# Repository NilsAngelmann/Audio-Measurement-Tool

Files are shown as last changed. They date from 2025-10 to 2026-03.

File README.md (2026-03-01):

# About

This fork focuses on the **stand-alone audio measurement tool** that was originally developed as part of the [“Making Music over the Internet”](https://github.com/StephanBorucki/MusizierenUeberDasInternet) project.

Here you will find detailed information such as the schematic, PCB layout, bill of materials, Arduino sketches, and usage instructions.

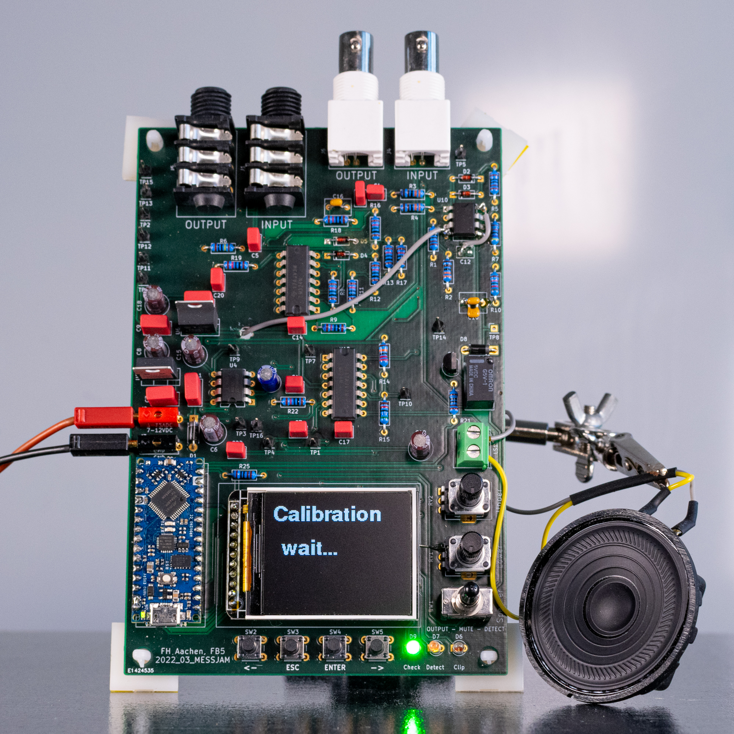
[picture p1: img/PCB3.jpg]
PCB


---

## Demo Video on YouTube 📺
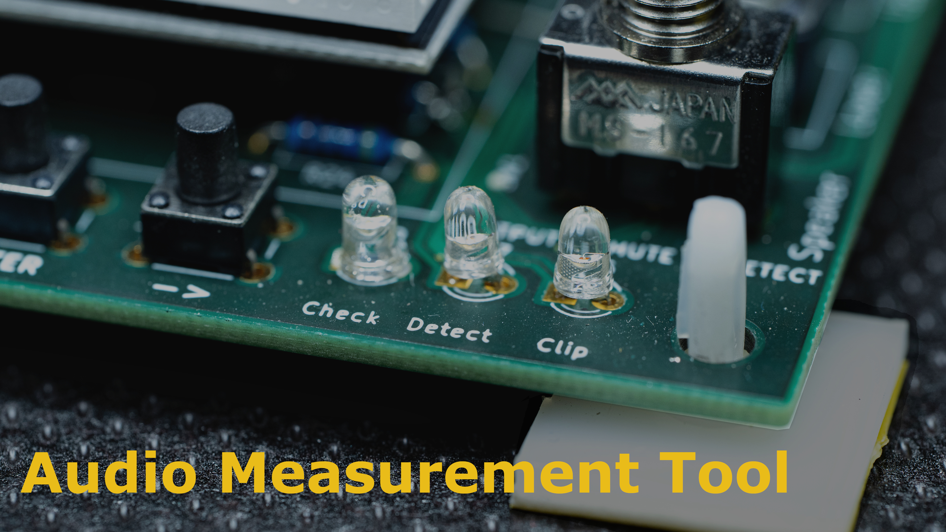
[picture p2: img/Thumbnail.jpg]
YouTube Video (https://www.youtube.com/watch?v=QHqr9eeyrQI)


---
## Files
- **Hardware:**
  - [2022](hardware/2022): Original version from 2022
    - Created with KiCad 8
    - Comments in German
    - Includes: Schematic, PCB Layout, Gerber Files, BOM
      
  - [2025](hardware/2025): Published version with corrections
    - Created with KiCad 9
    - Comments in English
    - Includes: Schematic
      
- **Firmware:**
  - [Measurement_03:](firmware/Measurement_03): Version 1.3
    - Measurement_03.ino: imports, pins, constants, variables, main loop of state machine
    - a_setup.ino: pin modes, welcome message on screen
    - b_menu.ino: menu to choose between error detection (DETECT) and latency measurement (BURST) mode
    - c_detect.ino: error detection (DETECT) mode
    - d_burst.ino: latency measurement (BURST) mode
   
> [!NOTE]
> Please refer to [Info2022](hardware/2022/Info2022.md) and [Info2025](hardware/2025/Info2025.md) before attempting to recreate this setup.

---
### License
This project is licensed under the [CERN Open Hardware License Version 2 – Permissive (CERN-OHL-P)](https://cern-ohl.web.cern.ch/).

Note: This license applies to the hardware design and firmware hosted here.
The printed article and its photos as published in Elektor remain subject to Elektor’s publishing rights.

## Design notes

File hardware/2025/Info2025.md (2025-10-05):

## Info regarding the corrected schematic

> [!IMPORTANT]
> This is only an updated schematic that does not include an updated pcb layout.

> [!TIP]
> This version should be used as a basis for all future revisions.

The following issues from the original version have been fixed in this update:
- [x] Supply voltage: 7 to 7.5 VDC rather than 7 to 12 VDC
- [ ] Switch SW1: Annotation flipped (should be output/mute/detect left to right) -> pcb layout (silkscreen)
- [ ] Polarity of electrolytic capacitors: No visible marking -> pcb layout (silkscreen)
- [ ] Test points: Only numbers -> pcb layout (silkscreen)
- [ ] Display footprint: Missing an unused pin -> only important for integtrated SD card reader
- [ ] DIP footprints: Too wide -> pcb layout
- [x] U10 (op amp): V+ and V- swapped
- [x] D5: wrong polarity
- [x] Clipping comparator: inputs swapped
- [x] Display SPI: MOSI and MISO swapped
- [ ] LED brightness -> adjust current-limiting resistors to taste

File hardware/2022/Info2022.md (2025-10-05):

## Info regarding the original version of the PCB from 2022

> [!CAUTION]
> This is the original version that includes several errors!

> [!WARNING]
> It is not advised to use this version as is!

- Supply voltage: 7 to 7.5 VDC rather than 7 to 12 VDC
- Switch SW1: Annotation flipped - should be output/mute/detect (left to right)
- Polarity of electrolytic capacitors: No visible marking - use GND plane as reference
- Test points: Only numbers - crossreference schematic for functions
- Display footprint: Missing an unused pin - ignore
- DIP footprints: Too wide - bend legs slightly appart, do not use sockets
- U10 (op amp): V+ and V- swapped - bend legs up and connect using wire
- D5: wrong polarity - solder in with opposing polarity
- Clipping comparator: inputs swapped - turn LED around and connect anode to +5V
- Display SPI: MOSI and MISO swapped - bridge both Arduino pins (MISO is not needed)
- LED brightness: depending on the used LEDs adjust their current-limiting resistors

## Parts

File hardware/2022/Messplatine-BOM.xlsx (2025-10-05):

Ref | Value | Quantity | Link
A1 | TFT-1.8-ST7735R | 1 | https://www.reichelt.de/entwicklerboards-display-led-1-8-128x160-st7735r-debo-tft-1-8-p192139.html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
A2 | Arduino_Nano_Every | 1 | https://www.reichelt.de/arduino-nano-every-atmega4809-mit-header-ard-nano-eve-h-p261301.html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
A | Header | 2 | https://www.reichelt.de/50pol-stiftleiste-gerade-rm-2-54-sl-1x50g-2-54-p19508.html?trstct=pol_0&nbc=1
A | Sockets | 3 | https://www.reichelt.de/20pol-buchsenleiste-gerade-rm-2-54-bl-1x20g-2-54-p6072.html?trstct=pol_1&nbc=1
C1 C5 C7 C12 C14 C17 C20 C22 | 100n | 8 | https://www.reichelt.de/mks02-pet-kondensator-100-nf-10-63-vdc-rm-2-5-mks02-63-100n-p12314.html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
C10 | 1n5 | 1 | https://www.reichelt.de/mks2-pet-kondensator-1-5-f-5-63-vdc-rm-5-mks2-63-1-5--p12348.html?trstct=pol_0&nbc=1
C13 | 10u | 1 | https://www.reichelt.de/elko-radial-10-f-16-v-rm-2-5-85-c-2000-h-20--m-a-10u-16-3-p228236.html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
C16 | 22p | 1 | https://www.reichelt.de/vielschicht-kerko-22pf-200v-125-c-c3c0g-22p-200-p206825.html?trstct=pos_4&nbc=1
C2 C4 | 47n | 2 | https://www.reichelt.de/mks02-pet-kondensator-47-nf-10-63-vdc-rm-2-5-mks02-63-47n-p12326.html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
C3 C9 C11 C21 | 470n | 4 | https://www.reichelt.de/folienkondensator-470nf-63v-rm5-mks2-63-470n-p12357.html?&trstct=pol_0&nbc=1
C6 C8 C15 C18 C19 | 100u | 5 | https://www.reichelt.de/elko-radial-100-f-16-v-rm-2-5-85-c-2000h-20--rad-100-16-p15101.html?trstct=pol_0&nbc=1
D1 D8 | 1N4001 | 2 | https://www.reichelt.de/gleichrichterdiode-50-v-1-a-do-41-1n-4001-p1723.html?&trstct=pos_0&nbc=1
D2 D3 D4 D5 | 1N4148 | 4 | https://www.reichelt.de/schalt-diode-100-v-150-ma-do-35-1n-4148-p1730.html?&trstct=pos_0&nbc=1
D6 | LED, green | 1 | https://www.reichelt.de/led-3-mm-bedrahtet-gruen-6500-mcd-30--wue-151033gs0300-p230890.html?trstct=pol_1&nbc=1
D7 | LED, yellow | 1 | https://www.reichelt.de/led-3-mm-bedrahtet-gelb-850-mcd-30--wue-151033ys0300-p230892.html?trstct=pol_5&nbc=1
D8 | LED, red | 1 | https://www.reichelt.de/led-3-mm-bedrahtet-rot-850-mcd-30--wue-151033rs0300-p230891.html?trstct=pol_4&nbc=1
J1 J5 | TRS | 2 | https://www.reichelt.de/klinkeneinbaubuchse-6-35-mm-stereo-neutrik-nr-j6hf-p116984.html?trstct=pol_9&nbc=1
J2 | SKS-MPB1, black | 1 | https://www.reichelt.de/miniatur-pruefbuchse-2-mm-schwarz-mpb-1-sw-p12711.html?&trstct=pol_3&nbc=1
J3 | SKS-MPB1, red | 1 | https://www.reichelt.de/miniatur-pruefbuchse-2-mm-rot-mpb-1-rt-p12710.html?&trstct=pol_2&nbc=1
J4 J6 | BNC | 2 | https://www.reichelt.de/bnc-printeinbaubuchse-gewinkelt-50-ohm-ug-1094w1-p22018.html?trstct=pol_4&nbc=1
K1 | SPDT | 1 | https://www.reichelt.de/signalrelais-thd-5-vdc-1-a-1-wechsler-g5v-1-5dc-p243067.html?trstct=pol_3&nbc=1
LS1 | Screw terminal | 1 | https://www.reichelt.de/anschlussklemme-2-pol-rm-5-08-mm-90--lakl-1-5-2-5-08-p169871.html?trstct=pol_1&nbc=1
LS | loudspeaker | 1 | https://www.reichelt.de/kleinlautsprecher-lsm-50m-k-f-0-5w-50ohm-lsm-50m-k-f-p145865.html?trstct=pol_6&nbc=1
Q1 | BC550 | 1 | https://www.reichelt.de/bipolartransistor-npn-45v-0-1a-hfe-420-800-0-625w-to-9-bc-550c-p5014.html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
R1 R5 R21 R25 | 1k | 4 | https://www.reichelt.de/widerstand-metallschicht-1-00-kohm-0207-0-6-w-1--metall-1-00k-p11403.html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
R10 | 82k | 1 | https://www.reichelt.de/widerstand-metallschicht-82-0-kohm-0207-0-6-w-1--metall-82-0k-p11999.html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
R14 | 220k | 1 | https://www.reichelt.de/widerstand-metallschicht-220-kohm-0207-0-6-w-1--metall-220k-p11628.html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
R15 | 56k | 1 | https://www.reichelt.de/widerstand-metallschicht-56-0-kohm-0207-0-6-w-1--metall-56-0k-p11879.html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
R2 R3 R4 | 3k3 | 3 | https://www.reichelt.de/widerstand-metallschicht-3-30-kohm-0207-0-6-w-1--metall-3-30k-p11693.html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
R20 R23 R24 | 4k7 | 3 | https://www.reichelt.de/widerstand-metallschicht-4-70-kohm-0207-0-6-w-1--metall-4-70k-p11784.html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
R6 | 1M | 1 | https://www.reichelt.de/widerstand-metallschicht-1-0-mohm-0207-0-6-w-1--metall-1-00m-p11404.html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
R7 | 47k | 1 | https://www.reichelt.de/widerstand-metallschicht-47-0-kohm-0207-0-6-w-1--metall-47-0k-p11823.html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
R8 R9 R11 R12 R13 R16 R17 R18 R19 R22 | 10k | 10 | https://www.reichelt.de/widerstand-metallschicht-10-0-kohm-0207-0-6-w-1--metall-10-0k-p11449.html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
RV1 RV2 | 100k | 2 | https://www.reichelt.de/drehpotentiometer-mono-100-kohm-linear-6-mm-rk09k113-lin100k-p73818.html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
SW1 | ON-OFF-ON | 1 | https://www.reichelt.de/kippschalter-6-a-125-vac-1x-ein-aus-ein-ms-167-p13141.html?trstct=pol_1&nbc=1
SW2 SW3 SW4 SW5 | SW_Push | 4 | https://www.reichelt.de/kurzhubtaster-6x6mm-hoehe-8-0mm-12v-vertikal-taster-9305-p44586.html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
U10 | LM358 | 1 | https://www.reichelt.de/operationsverstaerker-2-fach-0-4-v-s-700-khz-pdip-8-lm-358-p-p187547.html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
U0 | (Socket DIP8) | 1 | https://www.reichelt.de/praezisionsfassung-8-polig-rm-2-54-mpe-001-1-008-3-p213777.html?trstct=pol_2&nbc=1
U11 U12 | LM324 | 2 | https://www.reichelt.de/operationsverstaerker-quad-1-2-mhz-dil-14-lm-324-n-p248019.html?trstct=pos_2&nbc=1
U0 | (Socket DIP14) | 2 | https://www.reichelt.de/praezisionsfassung-14-polig-rm-2-54-mpe-001-1-014-3-p213779.html?trstct=pol_1&nbc=1
U2 | L7805 | 1 | https://www.reichelt.de/spannungsregler-fest-5-v-to-220-mc-7805-actg-p189082.html?trstct=pos_4&nbc=1
U4 | ICL7660 | 1 | https://www.reichelt.de/dc-dc-einstellbar-1-5--12-v-1-5--12-v-dil-8-icl-7660-acpaz-p188882.html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
U6 | L7905 | 1 | https://www.reichelt.de/ldo-festspannungsregler-5-vout-1-aout-to-220-mc-7905-ctg-p189094.html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
Z | PCB holder | 4 | https://www.reichelt.de/selbstklebender-abstandshalter-hoehe-4-8mm-ahs-4-8-p53729.html?trstct=pol_14&nbc=1

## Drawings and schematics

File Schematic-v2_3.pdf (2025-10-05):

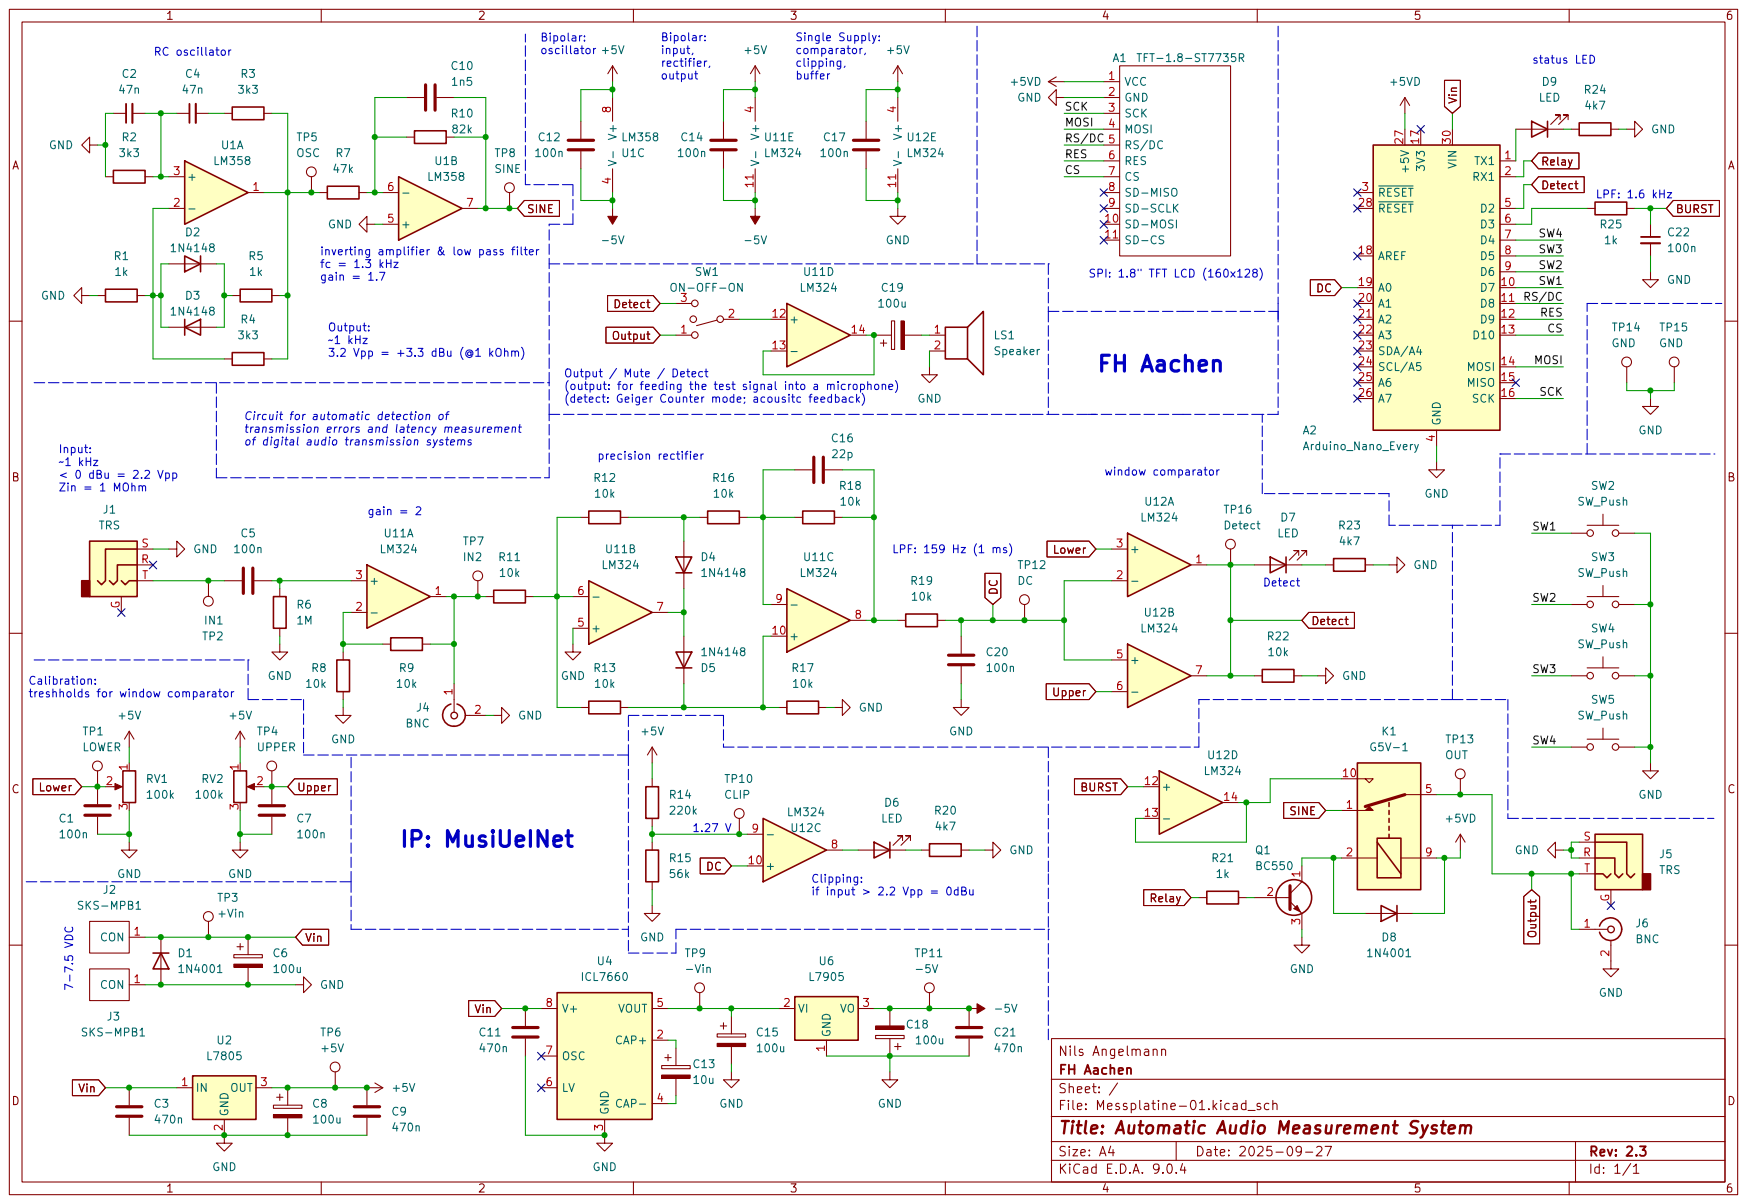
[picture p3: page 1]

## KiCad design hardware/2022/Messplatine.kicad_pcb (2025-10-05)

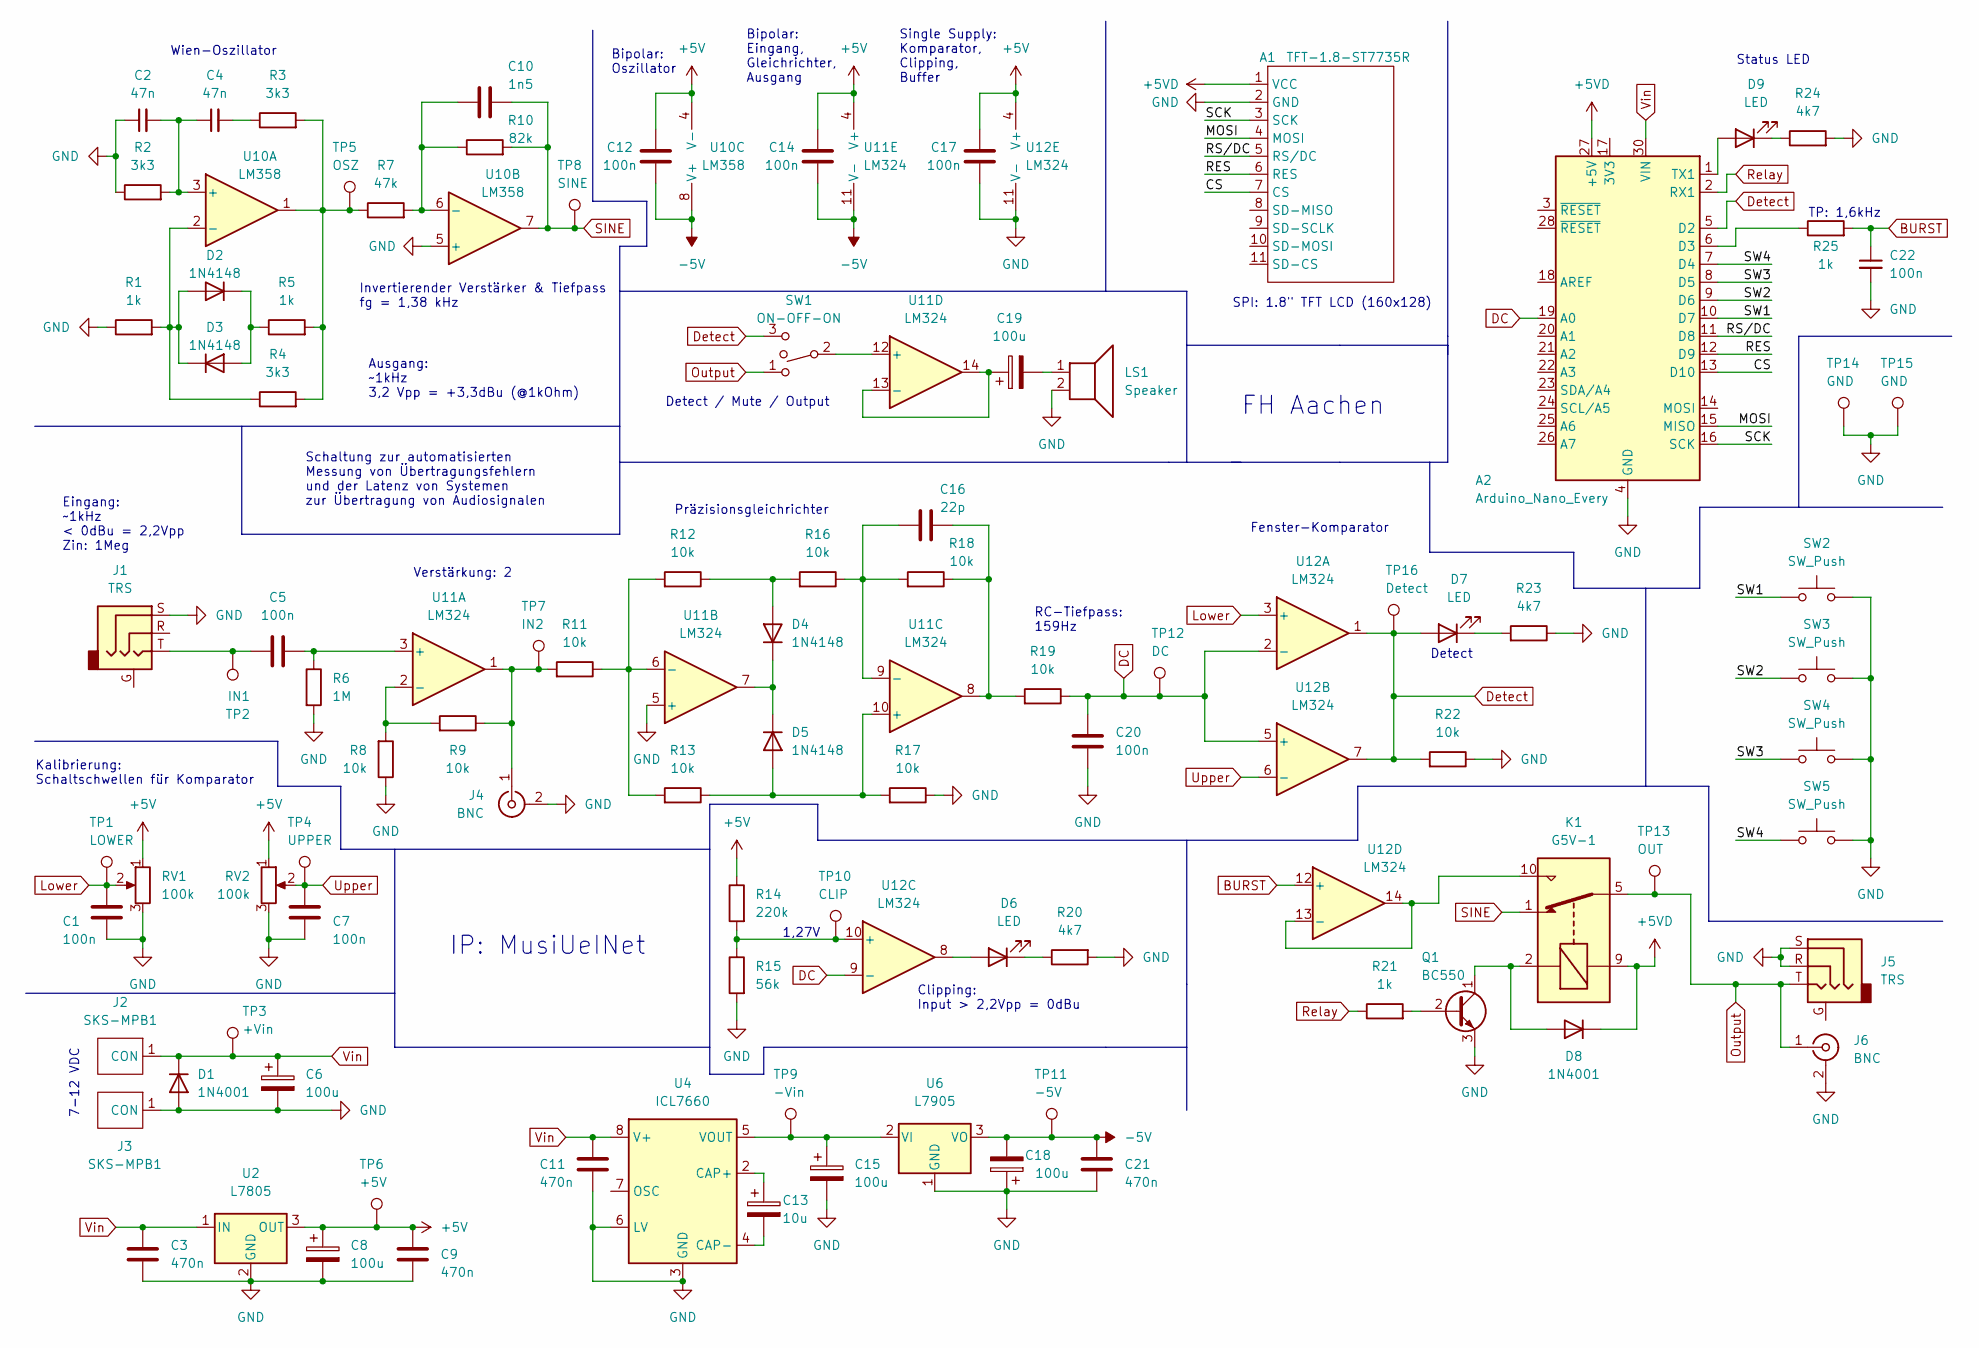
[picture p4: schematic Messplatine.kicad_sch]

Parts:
A1: TFT-1.8-ST7735R
A2: Arduino_Nano_Every; Arduino_Nano
C1, C5, C7, C12, C14, C17, C20, C22: 100n; C_Rect_L4.6mm_W3.0mm_P2.50mm_MKS02_FKP02
C2, C4: 47n; C_Rect_L4.6mm_W3.0mm_P2.50mm_MKS02_FKP02
C3, C9, C11, C21: 470n; C_Rect_L7.2mm_W3.5mm_P5.00mm_FKS2_FKP2_MKS2_MKP2
C6, C8, C15, C18, C19: 100u; C_Radial_D6.3mm_H11.0mm_P2.50mm
C10: 1n5; C_Rect_L7.2mm_W5.5mm_P5.00mm_FKS2_FKP2_MKS2_MKP2
C13: 10u; C_Radial_D5.0mm_H11.0mm_P2.00mm
C16: 22p; C_Rect_L7.0mm_W4.5mm_P5.00mm
D1, D8: 1N4001; D_DO-41_SOD81_P7.62mm_Horizontal
D2, D3, D4, D5: 1N4148; D_DO-35_SOD27_P7.62mm_Horizontal
D6, D7, D9: LED; LED_D3.0mm_Clear
J1, J5: TRS; Jack_6.35mm_Neutrik_NRJ6HF_Horizontal
J2, J3: SKS-MPB1
J4, J6: BNC; BKL-BNC
K1: G5V-1; Relay_SPDT_Omron_G5V-1
LS1: Speaker; TerminalBlock_Phoenix_MKDS-1,5-2-5.08_1x02_P5.08mm_Horizont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
Q1: BC550; TO-92
R1, R5, R21, R25: 1k; R_Axial_DIN0207_L6.3mm_D2.5mm_P10.16mm_Horizontal
R2, R3, R4: 3k3; R_Axial_DIN0207_L6.3mm_D2.5mm_P10.16mm_Horizontal
R6: 1M; R_Axial_DIN0207_L6.3mm_D2.5mm_P10.16mm_Horizontal
R7: 47k; R_Axial_DIN0207_L6.3mm_D2.5mm_P10.16mm_Horizontal
R8, R9, R11, R12, R13, R16, R17, R18, R19, R22: 10k; R_Axial_DIN0207_L6.3mm_D2.5mm_P10.16mm_Horizontal
R10: 82k; R_Axial_DIN0207_L6.3mm_D2.5mm_P10.16mm_Horizontal
R14: 220k; R_Axial_DIN0207_L6.3mm_D2.5mm_P10.16mm_Horizontal
R15: 56k; R_Axial_DIN0207_L6.3mm_D2.5mm_P10.16mm_Horizontal
R20, R23, R24: 4k7; R_Axial_DIN0207_L6.3mm_D2.5mm_P10.16mm_Horizontal
RV1, RV2: 100k; Potentiometer_Alps_RK09K_Single_Vertical
SW1: ON-OFF-ON; Miyama-MS-167
SW2, SW3, SW4, SW5: SW_Push; SW_PUSH_6mm_H8mm
TP1: LOWER; PinHeader_1x01_P2.54mm_Vertical
TP2: IN1; PinHeader_1x01_P2.54mm_Vertical
TP3: +Vin; PinHeader_1x01_P2.54mm_Vertical
TP4: UPPER; PinHeader_1x01_P2.54mm_Vertical
TP5: OSZ; PinHeader_1x01_P2.54mm_Vertical
TP6: +5V; PinHeader_1x01_P2.54mm_Vertical
TP7: IN2; PinHeader_1x01_P2.54mm_Vertical
TP8: SINE; PinHeader_1x01_P2.54mm_Vertical
TP9: -Vin; PinHeader_1x01_P2.54mm_Vertical
TP10: CLIP; PinHeader_1x01_P2.54mm_Vertical
TP11: -5V; PinHeader_1x01_P2.54mm_Vertical
TP12: DC; PinHeader_1x01_P2.54mm_Vertical
TP13: OUT; PinHeader_1x01_P2.54mm_Vertical
TP14, TP15: GND; PinHeader_1x01_P2.54mm_Vertical
TP16: Detect; PinHeader_1x01_P2.54mm_Vertical
U2: L7805; TO-220-3_Vertical
U4: ICL7660; DIP-8_W10.16mm
U6: L7905; TO-220-3_Vertical
U10: LM358; DIP-8_W10.16mm
U11, U12: LM324; DIP-14_W10.16mm

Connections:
+5V: C8.1, C9.1, C12.2, C14.2, C17.2, R14.1, RV1.1, RV2.1, TP6.1, U2.3 (OUT), U10.4 (V-), U11.4 (V+), U12.4 (V+)
+5VD: A1.1 (VCC), A2.27 (+5V), D8.1 (K), K1.9
-5V: C12.1, C14.1, C18.2, C21.1, TP11.1, U6.3 (VO), U10.8 (V+), U11.11 (V-)
/CS: A1.7 (CS), A2.13 (D10)
/MOSI: A1.4 (MOSI), A2.15 (MISO)
/RES: A1.6 (RES), A2.12 (D9)
/RS/DC: A1.5 (RS/DC), A2.11 (D8)
/SCK: A1.3 (SCK), A2.16 (SCK)
/SW1: A2.10 (D7), SW2.1
/SW2: A2.9 (D6), SW3.1
/SW3: A2.8 (D5), SW4.1
/SW4: A2.7 (D4), SW5.1
BURST: C22.1, R25.2, U12.12 (+)
DC: A2.19 (A0), C20.2, R19.1, TP12.1, U12.2 (-), U12.5 (+), U12.9 (-)
Detect: A2.5 (D2), D7.2 (A), R22.2, SW1.3, TP16.1, U12.1, U12.7
Lower: C1.2, RV1.2, TP1.1, U12.3 (+)
unnamed: A2.1 (TX1), D9.2 (A)
unnamed: A2.6 (D3), R25.1
unnamed: C2.2, C4.1, R2.2, U10.3 (+)
unnamed: C4.2, R3.1
unnamed: C5.1, J1.T, TP2.1
unnamed: C5.2, R6.1, U11.3 (+)
unnamed: C10.1, R7.2, R10.1, U10.6 (-)
unnamed: C13.1, U4.2 (CAP+)
unnamed: C13.2, U4.4 (CAP-)
unnamed: C15.1, TP9.1, U4.5 (VOUT), U6.2 (VI)
unnamed: C16.1, R16.1, R18.2, U11.9 (-)
unnamed: C16.2, R18.1, R19.2, U11.8
unnamed: C19.1, U11.13 (-), U11.14
unnamed: C19.2, LS1.1
unnamed: D2.1 (K), D3.2 (A), R5.1
unnamed: D2.2 (A), D3.1 (K), R1.2, R4.1, U10.2 (-)
unnamed: D4.1 (K), D5.1 (K), U11.7
unnamed: D4.2 (A), R12.1, R16.2
unnamed: D5.2 (A), R13.1, R17.2, U11.10 (+)
unnamed: D6.1 (K), R20.1
unnamed: D6.2 (A), U12.8
unnamed: D7.1 (K), R23.2
unnamed: D8.2 (A), K1.2, Q1.1 (C)
unnamed: D9.1 (K), R24.1
unnamed: J4.1 (In), R9.1, R11.2, TP7.1, U11.1
unnamed: K1.10, U12.13 (-), U12.14
unnamed: Q1.2 (B), R21.2
unnamed: R3.2, R4.2, R5.2, R7.1, TP5.1, U10.1
unnamed: R8.2, R9.2, U11.2 (-)
unnamed: R11.1, R12.2, R13.2, U11.6 (-)
unnamed: R14.2, R15.1, TP10.1, U12.10 (+)
unnamed: SW1.2, U11.12 (+)
Output: J5.T, J6.1 (In), K1.5, K1.6, SW1.1, TP13.1
Relay: A2.2 (RX1), R21.1
SINE: C10.2, K1.1, R10.2, TP8.1, U10.7
Upper: C7.2, RV2.2, TP4.1, U12.6 (-)
Vin: A2.30 (VIN), C3.1, C6.1, C11.1, D1.1 (K), J2.1 (CON), TP3.1, U2.1 (IN), U4.8 (V+)

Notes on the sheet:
Status LED
Verstärkung: 2
Bipolar: Oszillator
TP: 1,6kHz
Clipping: Input > 2,2Vpp = 0dBu
Schaltung zur automatisierten Messung von Übertragungsfehlern und der Latenz von Systemen zur Übertragung von Audiosignalen
Wien-Oszillator
Ausgang: ~1kHz 3,2 Vpp = +3,3dBu (@1kOhm)
Detect
Fenster-Komparator
FH Aachen
Detect / Mute / Output
Kalibrierung: Schaltschwellen für Komparator
RC-Tiefpass: 159Hz
Bipolar: Eingang, Gleichrichter, Ausgang
IP: MusiUeINet
Präzisionsgleichrichter
Single Supply: Komparator, Clipping, Buffer
Eingang: ~1kHz < 0dBu = 2,2Vpp Zin: 1Meg
1,27V
Invertierender Verstärker & Tiefpass fg = 1,38 kHz
SPI: 1.8" TFT LCD (160x128)
7-12 VDC

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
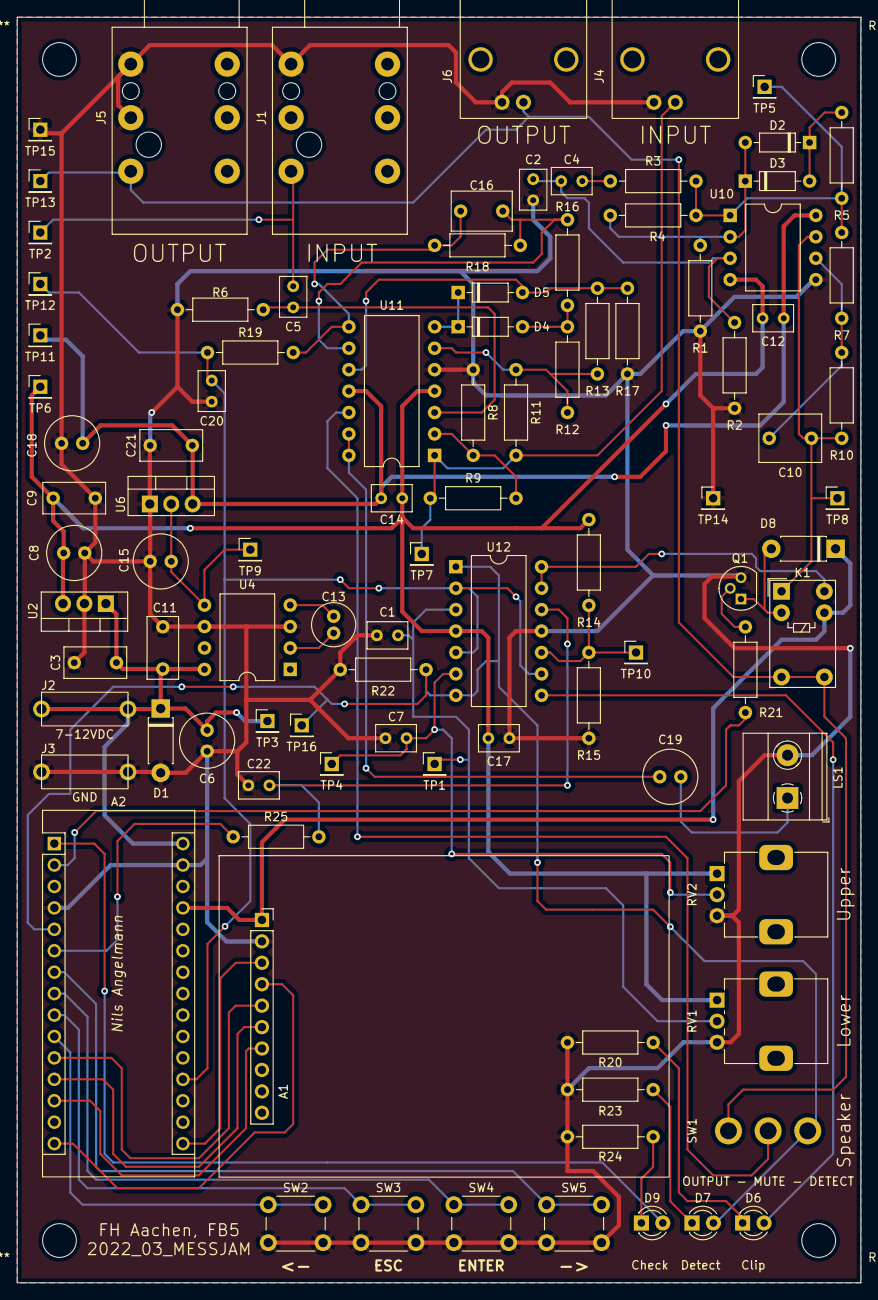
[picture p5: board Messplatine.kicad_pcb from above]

Board: 2 copper layers, 100.0 x 150.0 mm, 96 parts (0 on the bottom side), 54 nets.

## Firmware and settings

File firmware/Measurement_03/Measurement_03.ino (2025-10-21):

/*  FH Aachen
    Interdisciplinary Project: MusiUeNet
    (Automatic Audio Measurement System)

    Measuring PCB (and associated software) by Nils Angelmann - 2022-2025
*/


//////////////////////////
/////// HARDWARE /////////
//////////////////////////

// Imports for Display
#include <Adafruit_GFX.h>     // Core graphics library
#include <Adafruit_ST7735.h>  // Hardware-specific library for ST7735
#include <SPI.h>
#include <Fonts/FreeSans12pt7b.h>
#include <Fonts/FreeSansBold12pt7b.h>

// Display pins
#define TFT_CS 10
#define TFT_RST 9
#define TFT_DC 8

Adafruit_ST7735 tft = Adafruit_ST7735(TFT_CS, TFT_DC, TFT_RST);  // Create Display Object named tft

// Colors for Display
#define BLACK 0x0000
#define BLUE 0x001F
#define RED 0xF800
#define GREEN 0x07E0
#define CYAN 0x07FF
#define MAGENTA 0xF81F
#define YELLOW 0xFFE0
#define WHITE 0xFFFF

// Pins
#define LEFT 7   // button left
#define ESC 6    // button escape
#define ENTER 5  // button enter
#define RIGHT 4  // button right

#define BURST 3   // Burst Output (PWM)
#define DETECT 2  // Detect Input
#define RELAY 0   // Relay Output
#define LED 1     // LED (Check)
#define DC A0     // DC Voltage -> ADC (Analog input)

// Constants
#define holdoff 0    // hold-off between detected errors in ms -> max. 15 ms
#define debounce 15  // bounce time of switches in ms



//////////////////////////
/////// Variables ////////
//////////////////////////

byte mode = 0;                    // state machine: 0=menu, 1=detect, 2=burst
volatile unsigned int count = 0;  // error counter
unsigned int prev_count = 100;    // prev error counter -> detect changes -> update screen
unsigned long lastUI = 5000;      // timestamp of last display refresh
unsigned long duration = 0;       // counter for latency measurement
int baseline = 0;                 // low level (no input signal) -> noise floor
unsigned long latency[10];        // last 10 latency measurements in microseconds
float avgLatency = 0;             // average of last 10 latency measurements
float offset = 340;               // latency compensation in us -> experimentally choosen using loop-back


void setup() {
  Serial.begin(115200);  // for debugging
  startup();             // get everything ready
}



void loop() {  // basic state machine with 3 states

  if (mode == 0) {  // menu
    menuF();
  }

  else if (mode == 1) {  // detect
    detectF();
  }

  else if (mode == 2) {  // burst
    burstF();
  }
}

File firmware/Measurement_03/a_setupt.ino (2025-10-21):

void startup() {
  // Buttons -> input with internal pullup resistor
  pinMode(LEFT, INPUT_PULLUP);
  pinMode(ESC, INPUT_PULLUP);
  pinMode(ENTER, INPUT_PULLUP);
  pinMode(RIGHT, INPUT_PULLUP);

  // Burst Out -> test signal for latency measurement
  pinMode(BURST, OUTPUT);

  // Detect -> signal from comparator (error detection)
  pinMode(DETECT, INPUT);

  // Relay -> Burst / Sine
  pinMode(RELAY, OUTPUT);
  digitalWrite(RELAY, HIGH);

  // LED
  pinMode(LED, OUTPUT);
  digitalWrite(LED, HIGH);

  // Display -> show welcome text
  tft.initR(INITR_GREENTAB);
  tft.setRotation(3);
  tft.fillScreen(WHITE);
  tft.setTextColor(BLACK);
  tft.setFont(&FreeSansBold12pt7b);
  tft.setTextSize(1);
  tft.setCursor(20, 25);
  tft.print("FH Aachen");
  tft.setCursor(10, 55);
  tft.print("MusiUeINet");
  tft.setCursor(10, 85);
  tft.print("Messplatine");
  tft.setCursor(45, 115);
  tft.print("v 1.3");
  delay(3000);
  tft.fillScreen(BLACK);
  tft.setTextColor(WHITE, BLACK);
  digitalWrite(LED, LOW);
}
